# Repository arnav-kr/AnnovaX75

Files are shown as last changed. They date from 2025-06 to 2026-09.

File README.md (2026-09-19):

# Annova X75

A 75% Mechanical Keyboard, custom built from scratch.

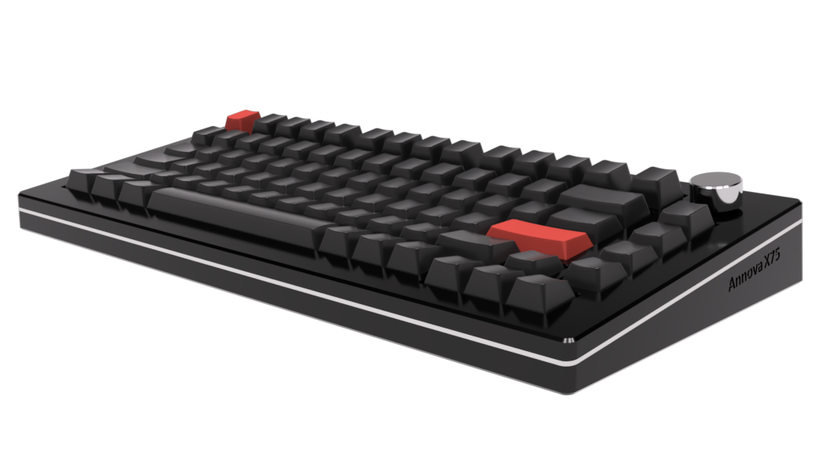
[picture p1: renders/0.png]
Annova X75


## Features
- 75% Exploded Layout
- Cherry MX Brown Switches
- RMK + Vial Firmware Support (Rust-based firmware with real-time Vial configuration)
- Hot-swappable Sockets
- Minimalist Sleek Design
- Customizable Knob
- Side mount USB-C Port
- 6° Typing Angle
- Sandwich Mount

## Build Guide

### PCB
The PCB is designed to be compatible with Cherry MX switches and features hot-swappable kalih sockets.
| Schematics |
| --- |
| Schematics |

| PCB (All Layers)|
| --- |
| PCB All Layers |

| PCB (Front Layer)|
| --- |
| PCB Front Layer |

| PCB (Back Layer)|
| --- |
| PCB Back Layer |

| PCB Render (Front)|
| --- |
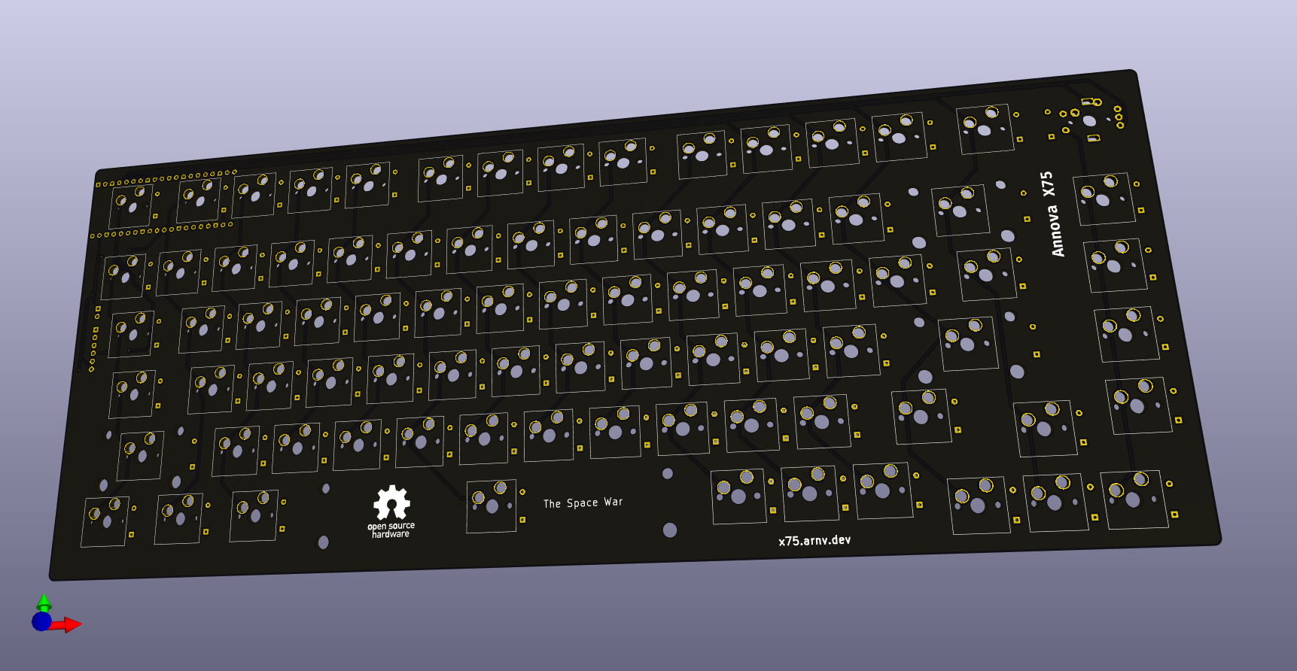
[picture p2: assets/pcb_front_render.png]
PCB Render Front
|  |

| PCB Render (Back)|
| --- |
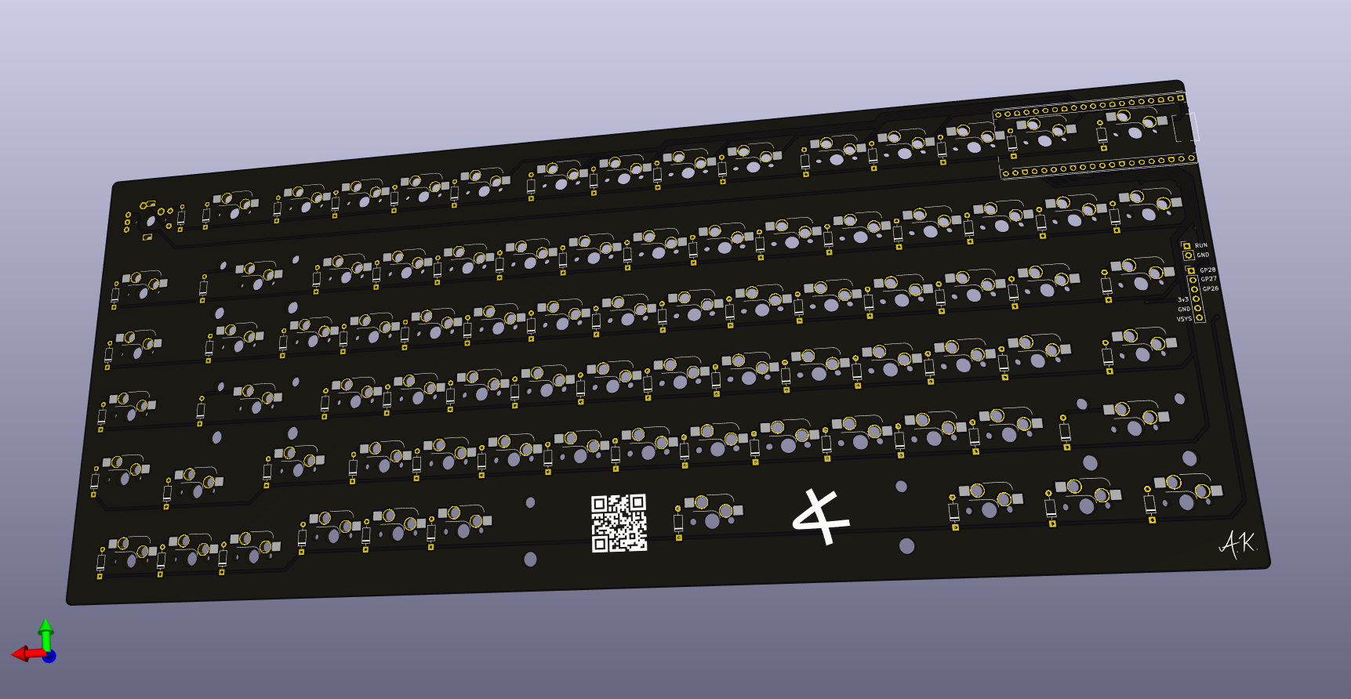
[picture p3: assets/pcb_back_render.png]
PCB Render Back
|  |

### Case

The case is designed to be 3D printed and features a sandwich mount design with a 6° typing angle. The bottom case, top case, plate, and knob are all designed to be printed.

| Case Full|
| --- |
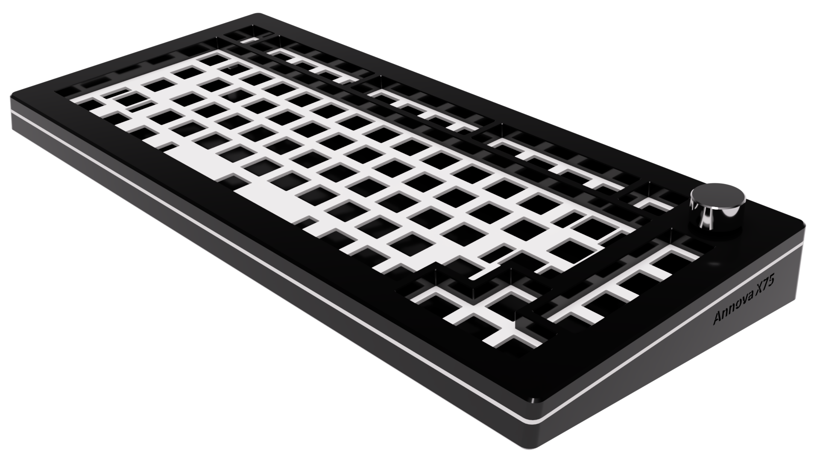
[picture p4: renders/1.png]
Case Full
|  |

| Case Top|
| --- |
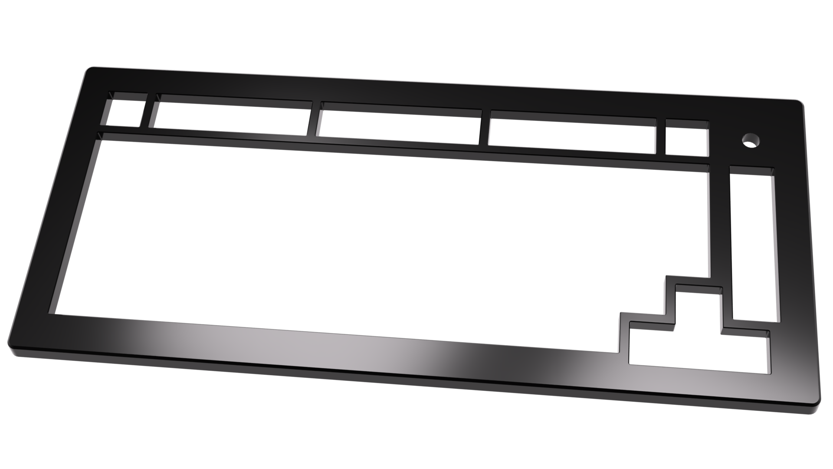
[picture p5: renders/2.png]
Case Top
|  |

| Plate|
| --- |
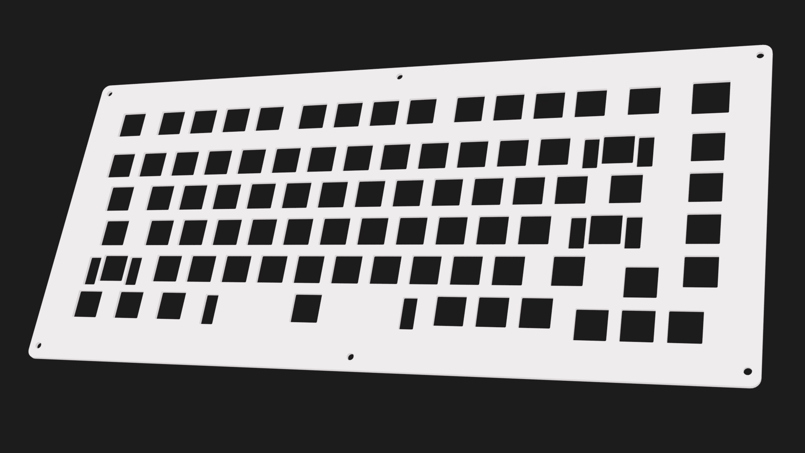
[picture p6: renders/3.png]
Plate
|  |

| Case Bottom|
| --- |
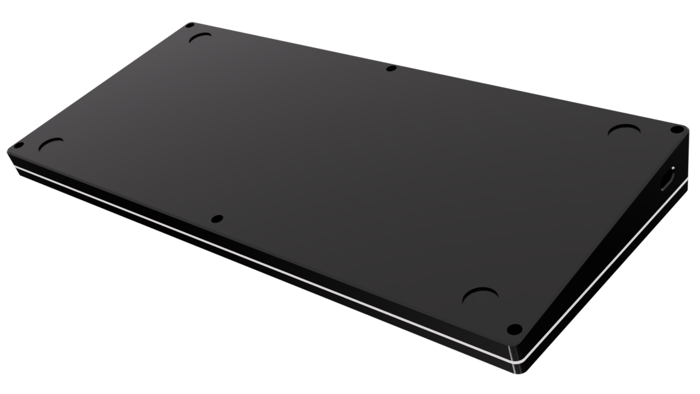
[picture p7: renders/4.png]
Case Bottom
|  |
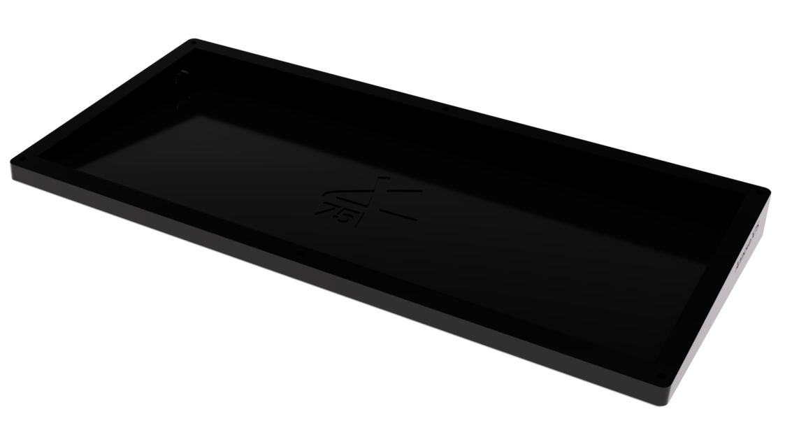
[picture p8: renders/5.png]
Case Bottom Alternative
|  |

| Knob|
| --- |
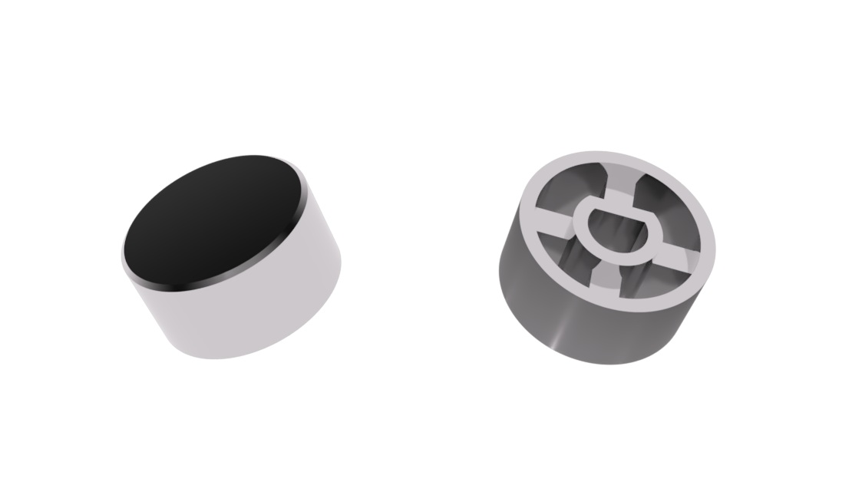
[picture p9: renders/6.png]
Knob
|  |

### BOM

| Item | Quantity | Cost (USD)* | Purchase Link |
| --- | --- | --- | --- |
| 1N4148 Diodes | 90 Pack  | 1.52 | https://stackskb.com/store/1n4148-through-hole-diode/ |
| Akko Bittersweet Switch | 90 Pack  | 34 | https://stackskb.com/store/akko-bittersweet-switch-pack-of-45/ |
| EC11 Rotary Encoder | 1 | 0.43 | https://www.flyrobo.in/ec11-rotary-encoder-half-shaft-handle-potentiometer-15mm |
| Orpheus Pico | 1 | - | Hack Club |
| Gateron Hotswap Sockets | 90 Pack  | 11.16 | https://stackskb.com/store/gateron-hotswap-sockets/ |
| Durock v2 Stabilizers Set | 1 | 17.98 | https://stackskb.com/store/durock-clear-screw-in-stabilizers-v2/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 |
| Keycap Set | 1 | 22.29 | https://curiositycaps.in/products/apollo-inspired-quality-cherry-doubleshot-pbt-keycaps?variant=51076299850009 |
| Socket Head M3x12 Screws | 3 | 0.3 | https://onlyscrews.in/products/hex-allen-socket-head-m3-x-12-screw-pack-of-20 |
| Socket Head M3x25 Screws | 3 | 0.3 | https://onlyscrews.in/products/m3-x-25mm-hex-allen-socket-head-ss-304-screw |
| M3 X 4mm Brass Threaded Inserts | 6 | 0.3 | https://onlyscrews.in/products/m4-x-4mm-brass-threaded-inserts |
| Bottom Case, Top Case, Plate, Knob | 1 | - | (3D Printed) |
| Bottom Rubber Feet | 4 | 2.13 | https://www.amazon.in/Miramar-Adhesive-Non-Slip-Furniture-Hemispherical/dp/B0BLN4TCPT |
| PCB | 1 | 58.2 | https://pcbpower.com |

for detailed bom check out [BOM.csv](BOM.csv)

Cost is as of 28/12/2025

## Author
[Arnav Kumar](https://github.com/arnav-kr)

## License
This project is licensed under the [AGPL-3.0 License](LICENSE).

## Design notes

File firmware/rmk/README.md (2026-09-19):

# Annova X75 RMK Firmware (Vial Enabled)

Firmware for the **Annova X75** mechanical keyboard built with [RMK](https://rmk.rs) (Rust Keyboard Firmware) and [Vial](https://get.vial.today) support.

## Hardware Specifications

- **MCU**: Raspberry Pi RP2040
- **Matrix**: 6 rows × 15 columns (COL2ROW)
  - Rows: `GP17`, `GP18`, `GP19`, `GP20`, `GP21`, `GP22` (`PIN_17` to `PIN_22`)
  - Columns: `GP0`, `GP1`, `GP15`, `GP14`, `GP13`, `GP12`, `GP11`, `GP10`, `GP9`, `GP8`, `GP7`, `GP6`, `GP5`, `GP4`, `GP3`
- **Rotary Encoder (EC11)**:
  - Pin A: `GP2` (`PIN_2`)
  - Pin B: `GP16` (`PIN_16`)
  - Push Button: Matrix `(0, 14)` (Row 0, Col 14)
  - Internal Pull-up: Enabled
  - Default Action: CCW = Volume Down, CW = Volume Up, Press = Mute
- **Bootloader / Bootmagic**:
  - Hold `Escape` (`(0, 0)`) during plug-in to enter RP2040 BOOTSEL mode.
  - Or press the physical RESET button on the back of the PCB.

## Vial Support

- Real-time on-the-fly keymap and rotary encoder remapping via the [Vial Web App](https://vial.rocks) or Vial desktop application.
- `vial.json` is embedded directly into the firmware binary (`build.rs`). No sideloading required.
- **Layers**: 4 layers enabled with persistent flash storage.
- **Unlock Combination**: Press `Escape` + `F1` (`(0, 0)` and `(0, 1)`) simultaneously to unlock secure features in Vial (matrix tester, etc.).

## Building the Firmware

Ensure you have Rust and the `thumbv6m-none-eabi` target installed:

```bash
rustup target add thumbv6m-none-eabi
```

### Build Release Binary

```bash
cargo build --release
```

### Generate `.uf2` file

Using `elf2uf2-rs`:

```bash
cargo install elf2uf2-rs
elf2uf2-rs target/thumbv6m-none-eabi/release/AnnovaX75 AnnovaX75.uf2
```

## Flashing the Keyboard

### Method 1: One-step USB Flash & Autoboot (Recommended)
`runner = "elf2uf2-rs -d"` is enabled by default in `.cargo/config.toml`.
1. Put the keyboard in BOOTSEL mode (hold `Escape` while plugging in, or press the button on the back of the PCB).
2. Run:
   ```bash
   cargo run --release
   ```
   `elf2uf2-rs` will detect the mounted Pico disk, flash the firmware, and **autoboot** the keyboard immediately.

### Method 2: Manual Drag and Drop
1. Build the `.uf2` file:
   ```bash
   cargo build --release
   elf2uf2-rs target/thumbv6m-none-eabi/release/AnnovaX75 AnnovaX75.uf2
   ```
2. Hold down `Escape` while plugging in the keyboard.
3. Drag and drop `AnnovaX75.uf2` onto the mounted `RPI-RP2` drive. The board will autoboot.

### Method 3: Debug Probe (probe-rs)
If using a Picoprobe or J-Link:

```bash
cargo run --release
```

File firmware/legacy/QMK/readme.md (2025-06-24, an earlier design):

# Annova X75 Rev 1

annova/x75/rev1

A 75% Mechanical Keyboard, custom built from scratch.

* Keyboard Maintainer: [Arnav Kumar](https://github.com/arnav-kr)
* Hardware Supported: RP2040
* Hardware Source: [arnav-kr/annovaX75](https://github.com/arnav-kr/annovaX75)

Make example for this keyboard (after setting up your build environment):

    make annova/x75/rev1:default

Flashing example for this keyboard:

    make annova/x75/rev1:default:flash

See the [build environment setup](https://docs.qmk.fm/#/getting_started_build_tools) and the [make instructions](https://docs.qmk.fm/#/getting_started_make_guide) for more information. Brand new to QMK? Start with our [Complete Newbs Guide](https://docs.qmk.fm/#/newbs).

## Bootloader

Enter the bootloader in 3 ways:

* **Bootmagic reset**: Hold down the key at (0,0) in the matrix (usually the top left key or Escape) and plug in the keyboard
* **Physical reset button**: Briefly press the button on the back of the PCB - some may have pads you must short instead
* **Keycode in layout**: Press the key mapped to `QK_BOOT` if it is available

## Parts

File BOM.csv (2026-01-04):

Item | Quantity | Cost (USD) | Purchase Link
1N4148 Diodes | 90 Pack | 1.52 | https://stackskb.com/store/1n4148-through-hole-diode/
Akko Bittersweet Switch | 90 Pack | 34 | https://stackskb.com/store/akko-bittersweet-switch-pack-of-45/
EC11 Rotary Encoder | 1 | 0.43 | https://www.flyrobo.in/ec11-rotary-encoder-half-shaft-handle-potentiometer-15mm
Orpheus Pico | 1 | - | Hack Club
Gateron Hotswap Sockets | 90 Pack | 10.3 | https://stackskb.com/store/gateron-hotswap-sockets/
Durock v2 Stabilizers Set | 1 | 17.98 | https://stackskb.com/store/durock-clear-screw-in-stabilizers-v2/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
Keycap Set | 1 | 22.29 | https://curiositycaps.in/products/apollo-inspired-quality-cherry-doubleshot-pbt-keycaps?variant=51076299850009
Socket Head M3x12 Screws | 3x2 | 0.15 | https://omrook.com/ss-allen-bolt-m3-x-12mm-dia-3mm-length-12mm-stainless-steel-ss202-socket-head-cap-screws/
Socket Head M3x25 Screws | 3x2 | 0.2 | https://omrook.com/ss-allen-bolt-m3-x-25mm-dia-3mm-length-25mm-stainless-steel-ss202-socket-head-cap-screws/
M3 X 4mm Brass Threaded Inserts | 6x2 | 1 | https://omrook.com/m3-x-4-brass-threaded-inserts-nut-50pc/
Bottom Case, Top Case, Plate, Knob | 1 | - | (3D Printed)
PCB (PCB Power) | 1 | 58.2 | https://www.pcbpower.com/
 | Components Total: | 146.07
Shipping: | Omrook | 1.15
 | Stackskb | 0
 | FlyRobo | 0.67
 | Curiosity Caps | 0
 | PCB Power | 0
 | Shipping Total: | 1.82
 | Total: | 147.89

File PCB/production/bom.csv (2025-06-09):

Designator | Footprint | Quantity | Value | LCSC Part #
D1, D10, D11, D12, D13, D14, D15, D16, D17, D18, D19, D2, D20, D21, D22, D23, D24, D25, D26, D27, D28, D29, D3, D30, D31, D32, D33, D34, D35, D36, D37, D38, D39, D4, D40, D41, D42, D43, D44, D45, D46, D47, D48, D49, D5, D50, D51, D52, D53, D54, D55, D56, D57, D58, D59, D6, D60, D61, D62, D63, D64, D65, D66, D67, D68, D69, D7, D70, D71, D72, D73, D74, D75, D76, D77, D78, D79, D8, D80, D81, D82, D83, D9 | D_DO-35_SOD27_P7.62mm_Horizontal | 83 | 1N4148
J1 | PinHeader_1x06_P2.54mm_Vertical | 1 | Conn_01x06_Pin
J2 | PinHeader_1x02_P2.54mm_Vertical | 1 | Conn_01x02_Pin
SW1, SW10, SW11, SW12, SW13, SW14, SW16, SW17, SW18, SW19, SW2, SW20, SW21, SW22, SW23, SW24, SW25, SW26, SW27, SW28, SW3, SW30, SW32, SW33, SW34, SW35, SW36, SW37, SW38, SW39, SW4, SW40, SW41, SW42, SW43, SW45, SW47, SW48, SW49, SW5, SW50, SW51, SW52, SW53, SW54, SW55, SW56, SW57, SW59, SW6, SW61, SW62, SW63, SW64, SW65, SW66, SW67, SW68, SW69, SW7, SW70, SW72, SW73, SW78, SW79, SW8, SW80, SW81, SW82, SW83, SW9 | SW_Hotswap_Kailh_MX_Plated_1.00u_With_Switch | 71 | SW_Push
SW15 | Encoder_EC11_MX_Combo | 1 | RotaryEncoder_Switch
SW29 | SW_Hotswap_Kailh_MX_Plated_2.00u_With_Switch | 1 | SW_Push
SW31, SW44 | SW_Hotswap_Kailh_MX_Plated_1.50u_With_Switch | 2 | SW_Push
SW46, SW71 | SW_Hotswap_Kailh_MX_Plated_1.75u_With_Switch | 2 | SW_Push
SW58, SW60 | SW_Hotswap_Kailh_MX_Plated_2.25u_With_Switch | 2 | SW_Push
SW74, SW75, SW76 | SW_Hotswap_Kailh_MX_Plated_1.25u_With_Switch | 3 | SW_Push
SW77 | SW_Hotswap_Kailh_MX_Plated_6.25u_With_Switch | 1 | SW_Push
U1 | RaspberryPi_Pico_THT | 1 | RaspberryPi_Pico

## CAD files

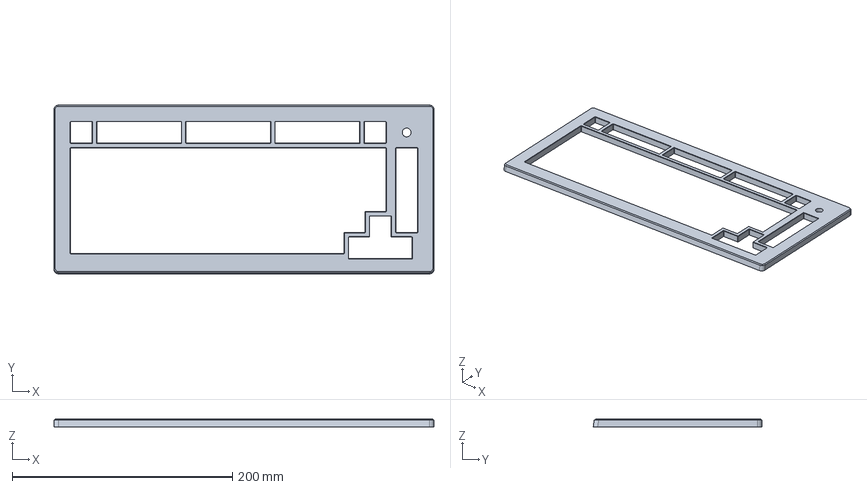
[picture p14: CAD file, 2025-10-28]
CAD/Top.step
344.9 x 153.1 x 7.00 mm

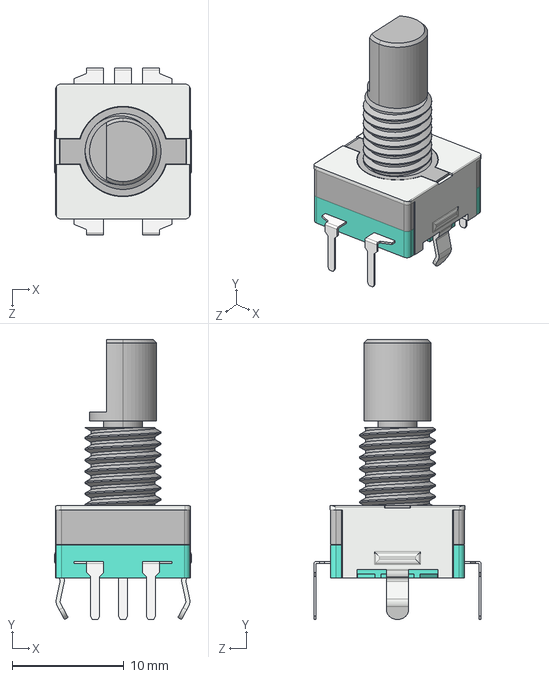
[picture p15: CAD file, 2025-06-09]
PCB/models/EC11.step
12.3 x 25.1 x 15.0 mm

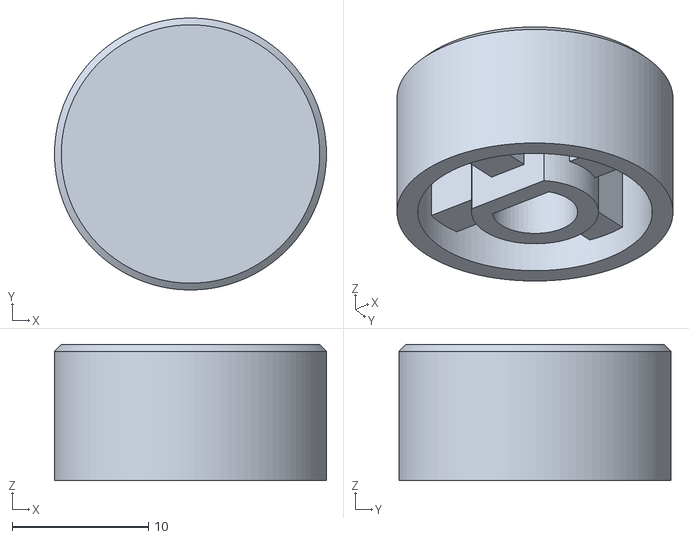
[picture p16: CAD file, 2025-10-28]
production/Knob.stl
20.0 x 20.0 x 10.0

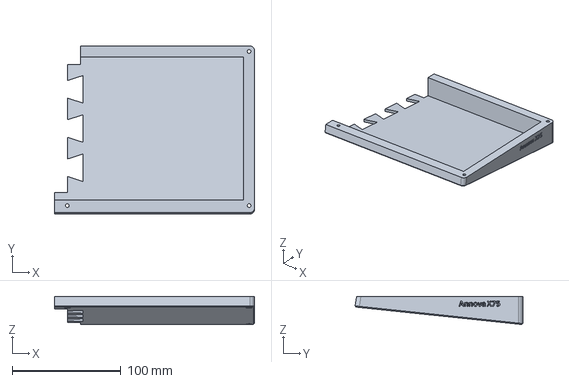
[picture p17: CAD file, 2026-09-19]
production/splitted/step/Bottom_Right.step
184.3 x 154.7 x 25.9 mm

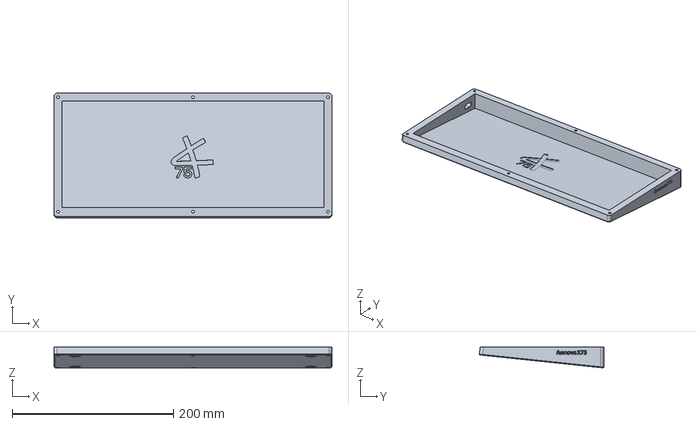
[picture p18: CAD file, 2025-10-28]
CAD/Bottom.step
344.8 x 154.7 x 25.9 mm

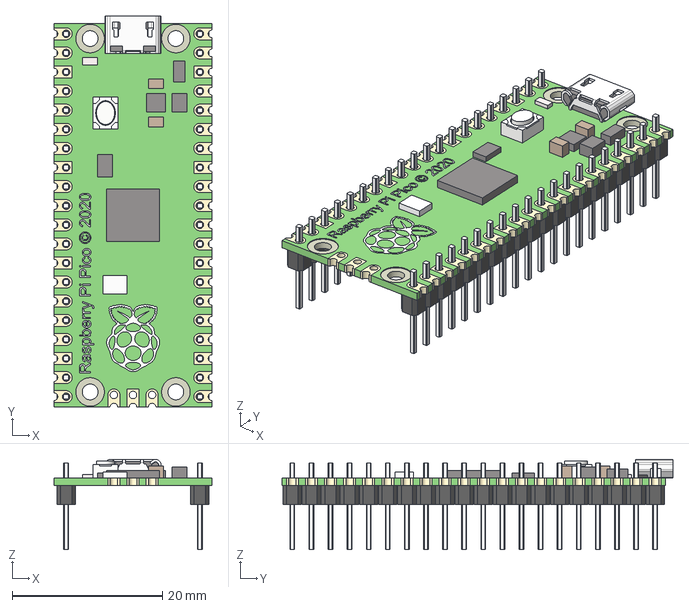
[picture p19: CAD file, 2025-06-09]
PCB/models/rpi_pico.step
21.0 x 52.0 x 12.0 mm
ножка x 20
ножка v3(Mirror) x 20

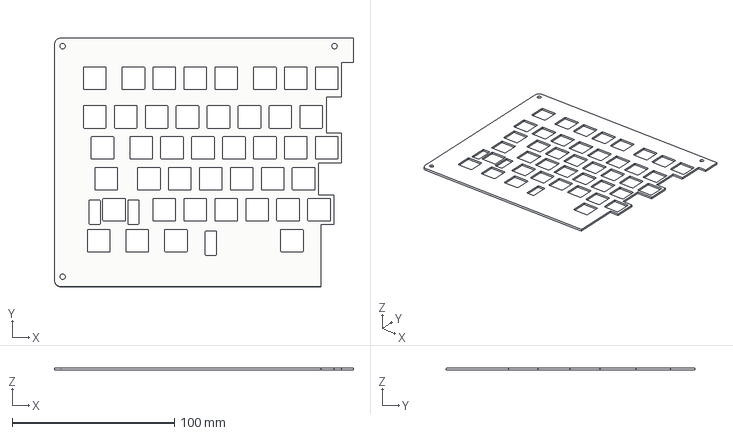
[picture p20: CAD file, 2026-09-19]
production/splitted/step/Plate_Right.step
184.1 x 153.3 x 1.50 mm

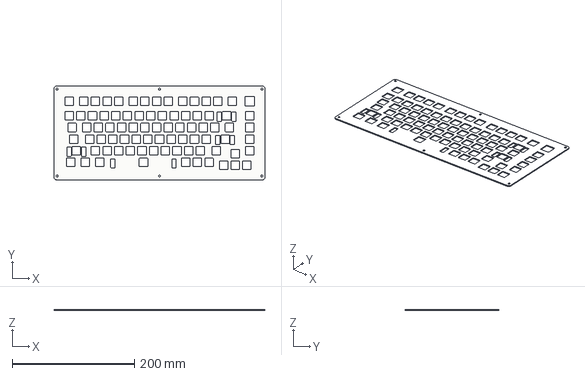
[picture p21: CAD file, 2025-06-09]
CAD/Plate.step
344.9 x 153.3 x 1.50 mm

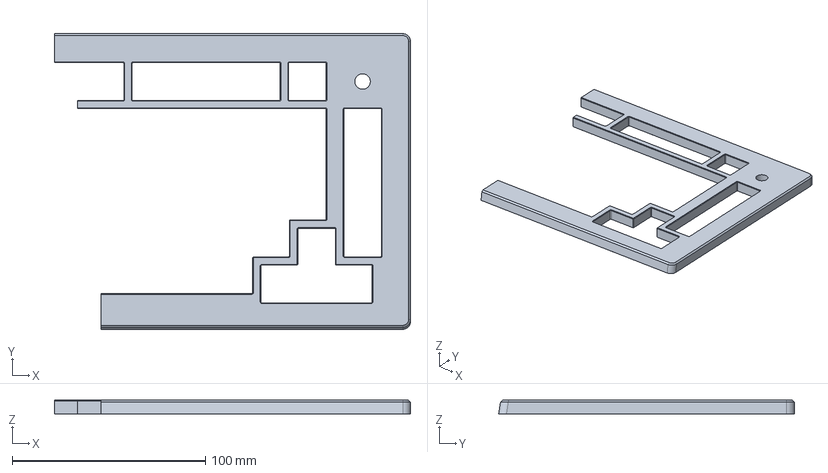
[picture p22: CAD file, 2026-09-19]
production/splitted/step/Top_Right.step
184.3 x 153.1 x 7.00 mm

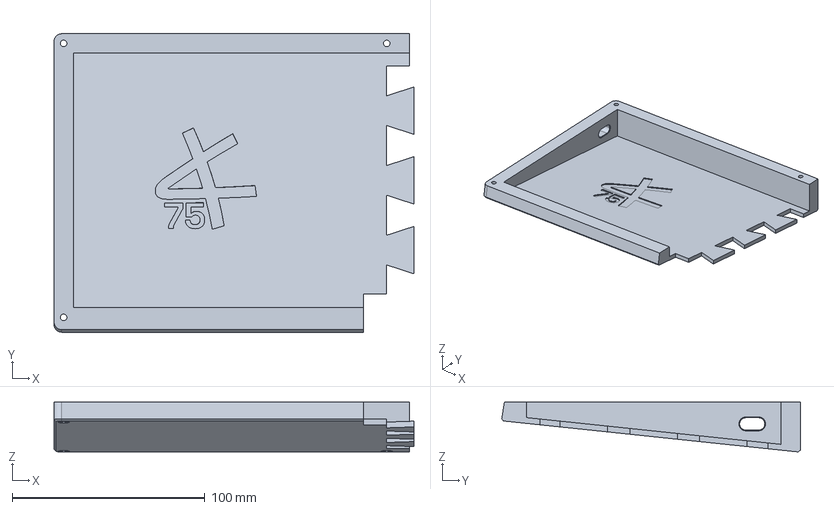
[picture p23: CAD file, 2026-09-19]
production/splitted/step/Bottom_Left.step
186.5 x 154.7 x 25.9 mm

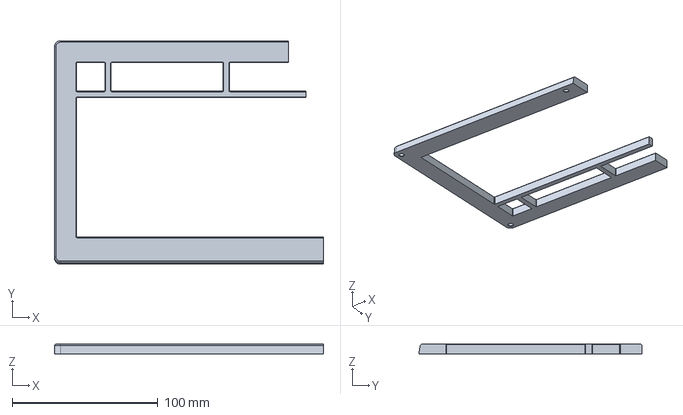
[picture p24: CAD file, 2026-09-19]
production/splitted/step/Top_Left.step
184.3 x 153.1 x 7.00 mm

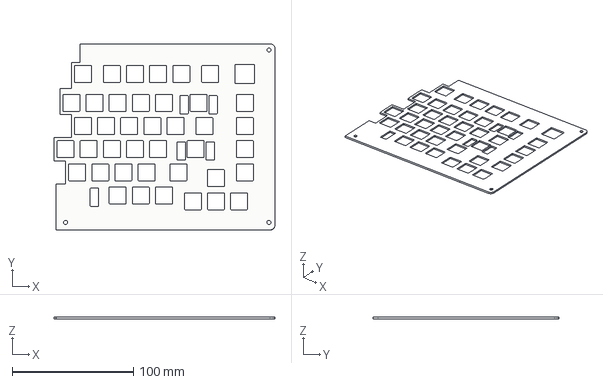
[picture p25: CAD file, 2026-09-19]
production/splitted/step/Plate_Left.step
182.0 x 153.3 x 1.50 mm

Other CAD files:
production/Top.stl
CAD/Knob.step
production/Bottom.stl
production/splitted/step/Knob.step
production/Plate.stl
production/splitted/stl/Bottom_Left.stl
production/splitted/stl/Bottom_Right.stl
production/splitted/stl/Knob.stl
production/splitted/stl/Plate_Left.stl
production/splitted/stl/Plate_Right.stl
production/splitted/stl/Top Right.stl
production/splitted/stl/Top_Left.stl

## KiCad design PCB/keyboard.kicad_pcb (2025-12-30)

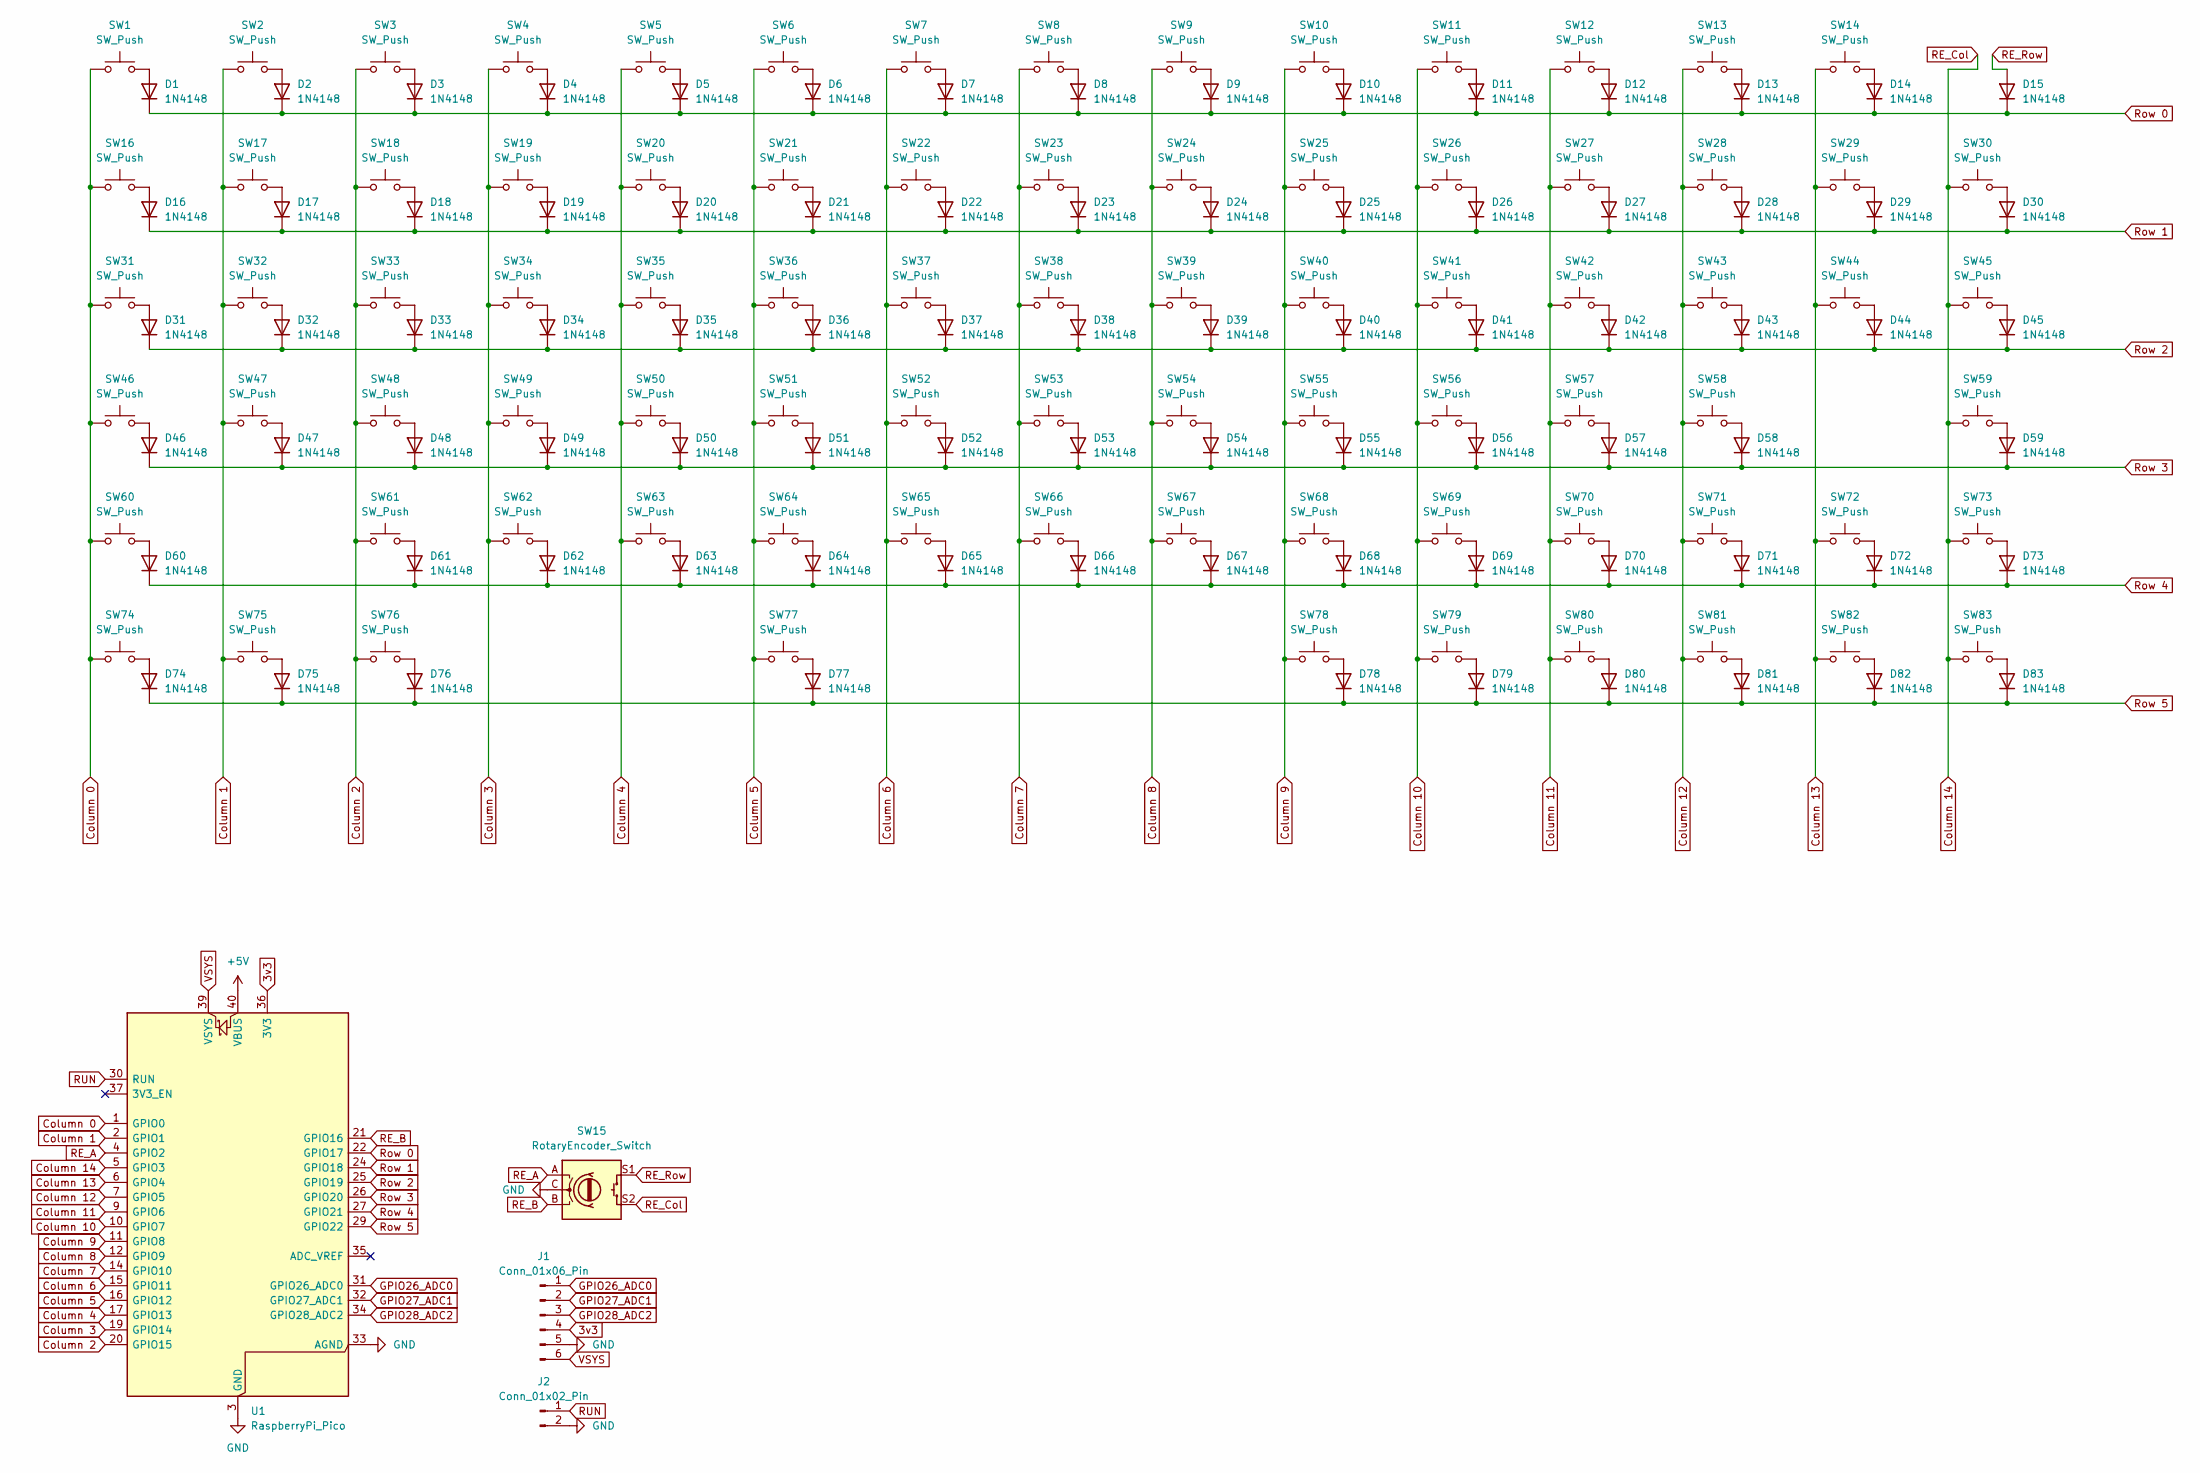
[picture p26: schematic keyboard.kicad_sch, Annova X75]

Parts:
D1, D2, D3, D4, D5, D6, D7, D8, D9, D10, D11, D12, D13, D14, D15, D16, D17, D18, D19, D20, D21, D22, D23, D24, D25, D26, D27, D28, D29, D30, D31, D32, D33, D34, D35, D36, D37, D38, D39, D40, D41, D42, D43, D44, D45, D46, D47, D48, D49, D50, D51, D52, D53, D54, D55, D56, D57, D58, D59, D60, D61, D62, D63, D64, D65, D66, D67, D68, D69, D70, D71, D72, D73, D74, D75, D76, D77, D78, D79, D80, D81, D82, D83: 1N4148; D_DO-35_SOD27_P7.62mm_Horizontal
J1: Conn_01x06_Pin; PinHeader_1x06_P2.54mm_Vertical
J2: Conn_01x02_Pin; PinHeader_1x02_P2.54mm_Vertical
SW1, SW2, SW3, SW4, SW5, SW6, SW7, SW8, SW9, SW10, SW11, SW12, SW13, SW14, SW16, SW17, SW18, SW19, SW20, SW21, SW22, SW23, SW24, SW25, SW26, SW27, SW28, SW30, SW32, SW33, SW34, SW35, SW36, SW37, SW38, SW39, SW40, SW41, SW42, SW43, SW45, SW47, SW48, SW49, SW50, SW51, SW52, SW53, SW54, SW55, SW56, SW57, SW59, SW61, SW62, SW63, SW64, SW65, SW66, SW67, SW68, SW69, SW70, SW72, SW73, SW78, SW79, SW80, SW81, SW82, SW83: SW_Push; SW_Hotswap_Kailh_MX_Plated_1.00u_With_Switch
SW15: RotaryEncoder_Switch; Encoder_EC11_MX_Combo
SW29: SW_Push; SW_Hotswap_Kailh_MX_Plated_2.00u_With_Switch
SW31, SW44: SW_Push; SW_Hotswap_Kailh_MX_Plated_1.50u_With_Switch
SW46, SW71: SW_Push; SW_Hotswap_Kailh_MX_Plated_1.75u_With_Switch
SW58, SW60: SW_Push; SW_Hotswap_Kailh_MX_Plated_2.25u_With_Switch
SW74, SW75, SW76: SW_Push; SW_Hotswap_Kailh_MX_Plated_1.25u_With_Switch
SW77: SW_Push; SW_Hotswap_Kailh_MX_Plated_6.25u_With_Switch
U1: RaspberryPi_Pico; RaspberryPi_Pico_THT

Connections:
3v3: J1.4, U1.36 (3V3)
+5V: U1.40 (VBUS)
Column 0: SW1.1, SW16.1, SW31.1, SW46.1, SW60.1, SW74.1, U1.1 (GPIO0)
Column 1: SW2.1, SW17.1, SW32.1, SW47.1, SW75.1, U1.2 (GPIO1)
Column 2: SW3.1, SW18.1, SW33.1, SW48.1, SW61.1, SW76.1, U1.20 (GPIO15)
Column 3: SW4.1, SW19.1, SW34.1, SW49.1, SW62.1, U1.19 (GPIO14)
Column 4: SW5.1, SW20.1, SW35.1, SW50.1, SW63.1, U1.17 (GPIO13)
Column 5: SW6.1, SW21.1, SW36.1, SW51.1, SW64.1, SW77.1, U1.16 (GPIO12)
Column 6: SW7.1, SW22.1, SW37.1, SW52.1, SW65.1, U1.15 (GPIO11)
Column 7: SW8.1, SW23.1, SW38.1, SW53.1, SW66.1, U1.14 (GPIO10)
Column 8: SW9.1, SW24.1, SW39.1, SW54.1, SW67.1, U1.12 (GPIO9)
Column 9: SW10.1, SW25.1, SW40.1, SW55.1, SW68.1, SW78.1, U1.11 (GPIO8)
Column 10: SW11.1, SW26.1, SW41.1, SW56.1, SW69.1, SW79.1, U1.10 (GPIO7)
Column 11: SW12.1, SW27.1, SW42.1, SW57.1, SW70.1, SW80.1, U1.9 (GPIO6)
Column 12: SW13.1, SW28.1, SW43.1, SW58.1, SW71.1, SW81.1, U1.7 (GPIO5)
Column 13: SW14.1, SW29.1, SW44.1, SW72.1, SW82.1, U1.6 (GPIO4)
Column 14: SW15.S2, SW30.1, SW45.1, SW59.1, SW73.1, SW83.1, U1.5 (GPIO3)
GND: J1.5, J2.2, SW15.C, U1.3 (GND), U1.8 (GND), U1.13 (GND), U1.18 (GND), U1.23 (GND), U1.28 (GND), U1.33 (AGND), U1.38 (GND)
GPIO26_ADC0: J1.1, U1.31 (GPIO26_ADC0)
GPIO27_ADC1: J1.2, U1.32 (GPIO27_ADC1)
GPIO28_ADC2: J1.3, U1.34 (GPIO28_ADC2)
unnamed: D1.2 (A), SW1.2
unnamed: D2.2 (A), SW2.2
unnamed: D3.2 (A), SW3.2
unnamed: D4.2 (A), SW4.2
unnamed: D5.2 (A), SW5.2
unnamed: D6.2 (A), SW6.2
unnamed: D7.2 (A), SW7.2
unnamed: D8.2 (A), SW8.2
unnamed: D9.2 (A), SW9.2
unnamed: D10.2 (A), SW10.2
unnamed: D11.2 (A), SW11.2
unnamed: D12.2 (A), SW12.2
unnamed: D13.2 (A), SW13.2
unnamed: D14.2 (A), SW14.2
unnamed: D16.2 (A), SW16.2
unnamed: D17.2 (A), SW17.2
unnamed: D18.2 (A), SW18.2
unnamed: D19.2 (A), SW19.2
unnamed: D20.2 (A), SW20.2
unnamed: D21.2 (A), SW21.2
unnamed: D22.2 (A), SW22.2
unnamed: D23.2 (A), SW23.2
unnamed: D24.2 (A), SW24.2
unnamed: D25.2 (A), SW25.2
unnamed: D26.2 (A), SW26.2
unnamed: D27.2 (A), SW27.2
unnamed: D28.2 (A), SW28.2
unnamed: D29.2 (A), SW29.2
unnamed: D30.2 (A), SW30.2
unnamed: D31.2 (A), SW31.2
unnamed: D32.2 (A), SW32.2
unnamed: D33.2 (A), SW33.2
unnamed: D34.2 (A), SW34.2
unnamed: D35.2 (A), SW35.2
unnamed: D36.2 (A), SW36.2
unnamed: D37.2 (A), SW37.2
unnamed: D38.2 (A), SW38.2
unnamed: D39.2 (A), SW39.2
unnamed: D40.2 (A), SW40.2
unnamed: D41.2 (A), SW41.2
unnamed: D42.2 (A), SW42.2
unnamed: D43.2 (A), SW43.2
unnamed: D44.2 (A), SW44.2
unnamed: D45.2 (A), SW45.2
unnamed: D46.2 (A), SW46.2
unnamed: D47.2 (A), SW47.2
unnamed: D48.2 (A), SW48.2
unnamed: D49.2 (A), SW49.2
unnamed: D50.2 (A), SW50.2
unnamed: D51.2 (A), SW51.2
unnamed: D52.2 (A), SW52.2
unnamed: D53.2 (A), SW53.2
unnamed: D54.2 (A), SW54.2
unnamed: D55.2 (A), SW55.2
unnamed: D56.2 (A), SW56.2
unnamed: D57.2 (A), SW57.2
unnamed: D58.2 (A), SW58.2
unnamed: D59.2 (A), SW59.2
unnamed: D60.2 (A), SW60.2
unnamed: D61.2 (A), SW61.2
unnamed: D62.2 (A), SW62.2
unnamed: D63.2 (A), SW63.2
unnamed: D64.2 (A), SW64.2
unnamed: D65.2 (A), SW65.2
unnamed: D66.2 (A), SW66.2
unnamed: D67.2 (A), SW67.2
unnamed: D68.2 (A), SW68.2
unnamed: D69.2 (A), SW69.2
unnamed: D70.2 (A), SW70.2
unnamed: D71.2 (A), SW71.2
unnamed: D72.2 (A), SW72.2
unnamed: D73.2 (A), SW73.2
unnamed: D74.2 (A), SW74.2
unnamed: D75.2 (A), SW75.2
unnamed: D76.2 (A), SW76.2
unnamed: D77.2 (A), SW77.2
unnamed: D78.2 (A), SW78.2
unnamed: D79.2 (A), SW79.2
unnamed: D80.2 (A), SW80.2
unnamed: D81.2 (A), SW81.2
unnamed: D82.2 (A), SW82.2
unnamed: D83.2 (A), SW83.2
RE_A: SW15.A, U1.4 (GPIO2)
RE_B: SW15.B, U1.21 (GPIO16)
RE_Row: D15.2 (A), SW15.S1
RUN: J2.1, U1.30 (RUN)
Row 0: D1.1 (K), D2.1 (K), D3.1 (K), D4.1 (K), D5.1 (K), D6.1 (K), D7.1 (K), D8.1 (K), D9.1 (K), D10.1 (K), D11.1 (K), D12.1 (K), D13.1 (K), D14.1 (K), D15.1 (K), U1.22 (GPIO17)
Row 1: D16.1 (K), D17.1 (K), D18.1 (K), D19.1 (K), D20.1 (K), D21.1 (K), D22.1 (K), D23.1 (K), D24.1 (K), D25.1 (K), D26.1 (K), D27.1 (K), D28.1 (K), D29.1 (K), D30.1 (K), U1.24 (GPIO18)
Row 2: D31.1 (K), D32.1 (K), D33.1 (K), D34.1 (K), D35.1 (K), D36.1 (K), D37.1 (K), D38.1 (K), D39.1 (K), D40.1 (K), D41.1 (K), D42.1 (K), D43.1 (K), D44.1 (K), D45.1 (K), U1.25 (GPIO19)
Row 3: D46.1 (K), D47.1 (K), D48.1 (K), D49.1 (K), D50.1 (K), D51.1 (K), D52.1 (K), D53.1 (K), D54.1 (K), D55.1 (K), D56.1 (K), D57.1 (K), D58.1 (K), D59.1 (K), U1.26 (GPIO20)
Row 4: D60.1 (K), D61.1 (K), D62.1 (K), D63.1 (K), D64.1 (K), D65.1 (K), D66.1 (K), D67.1 (K), D68.1 (K), D69.1 (K), D70.1 (K), D71.1 (K), D72.1 (K), D73.1 (K), U1.27 (GPIO21)
Row 5: D74.1 (K), D75.1 (K), D76.1 (K), D77.1 (K), D78.1 (K), D79.1 (K), D80.1 (K), D81.1 (K), D82.1 (K), D83.1 (K), U1.29 (GPIO22)
VSYS: J1.6, U1.39 (VSYS)

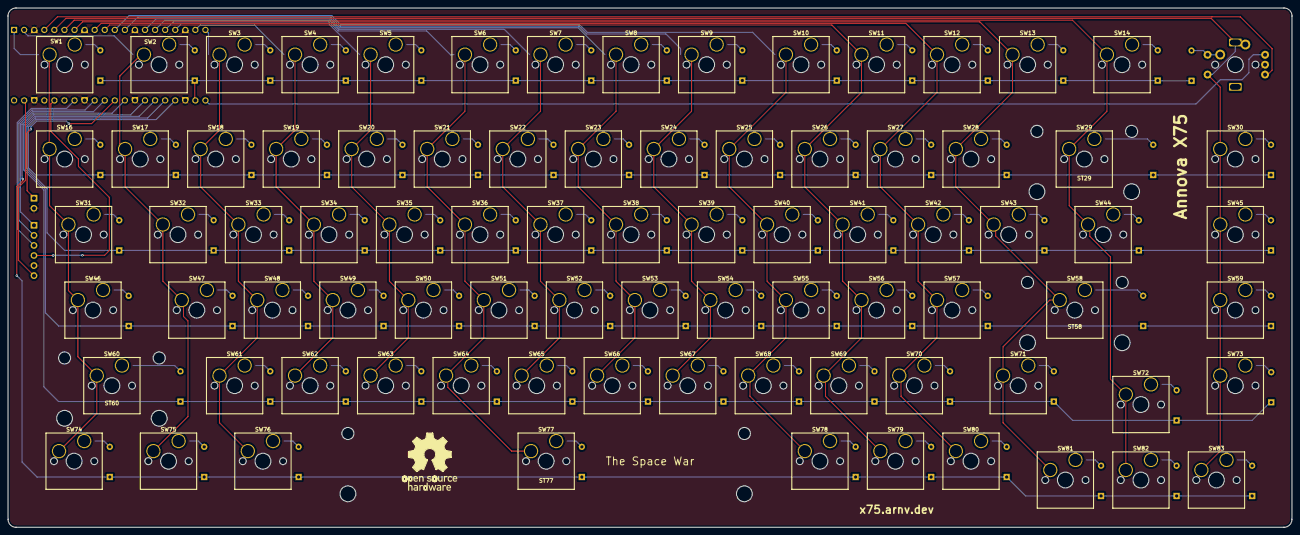
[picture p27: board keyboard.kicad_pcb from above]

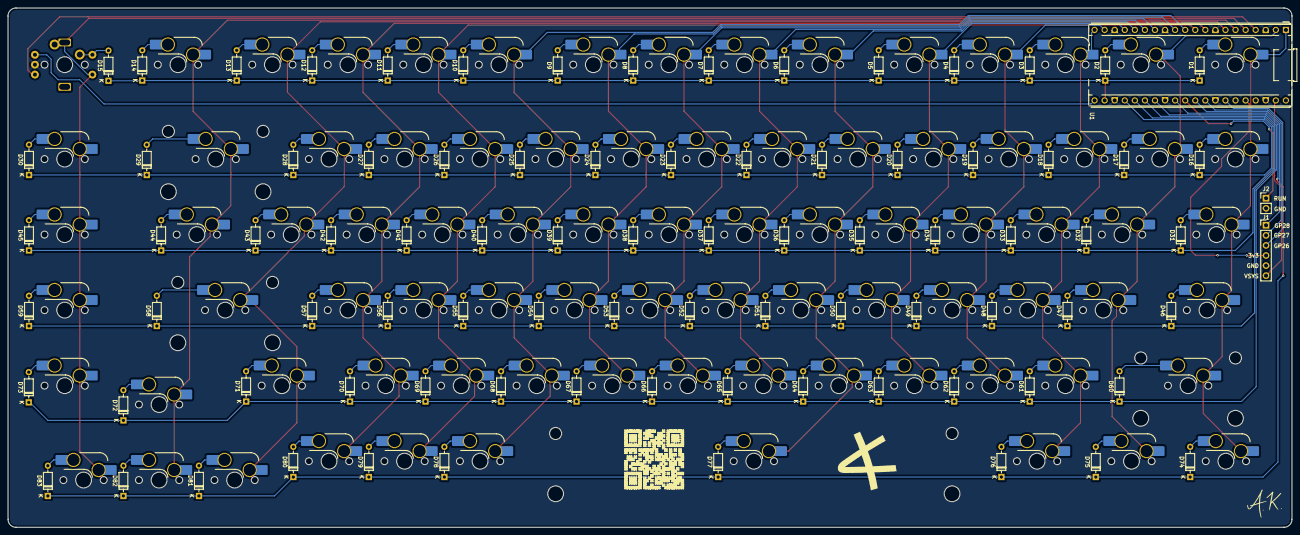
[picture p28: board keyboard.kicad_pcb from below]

Board: 2 copper layers, 323.9 x 131.0 mm, 173 parts (86 on the bottom side), 113 nets.

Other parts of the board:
ST29, ST58, ST60: Stabilizer_Cherry_MX_2.00u
ST77: Stabilizer_Cherry_MX_6.25u

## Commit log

2025-06-09 init: project
    [Bottom.step, Bottom.stl, EC11.step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]
2025-10-28 feat: update CAD models
    [Bottom.step, Bottom.stl, Knob.step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]
2025-10-28 feat: update pcb render
2025-10-30 feat: update pcb renders
2025-10-30 feat: update keyboard pcb and production files
    [keyboard.kicad_pcb]
2025-10-30 docs: update bom
2025-10-30 docs: bom file
    [BOM.csv]
2025-10-30 docs: update bom with shipping
    [BOM.csv]
2025-10-30 docs: update readme bom
2025-11-19 feat: production files, bom changes
    [BOM.csv, Bottom.stl, Knob.stl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]
2025-12-30 update gerbers
    [keyboard.kicad_pcb]
2026-01-04 docs: update BOM.csv
    [BOM.csv]
2026-07-31 cut models to fit in printer bed
    [Bottom_Left.step, Bottom_Left.stl, Bottom_Right.step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]
2026-09-19 experimental RMK support init
    [Bottom_Left.step, Bottom_Right.step, Knob.step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]
